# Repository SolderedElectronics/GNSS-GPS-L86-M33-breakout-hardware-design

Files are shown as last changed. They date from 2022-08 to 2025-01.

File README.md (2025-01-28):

# GNSS GPS L86-M33 breakout Hardware Design

## About the Product

| GNSS GPS L86-M33 breakout Image |
| :----------------------------------------------------------: |
| [Buy GNSS GPS L86-M33 breakout](https://www.solde.red/333201) |

Global Navigation Satellite Systems (GNSS), or as we all like to call it “GPS,” enable precise location determination on Earth. Thanks to this module, you can use GNSS for your project and employ the device for asset tracking or create a wearable device. The module is small, energy-efficient, highly effective, and easy to use thanks to its built-in antenna.

L86-M33 is a GNSS receiver, meaning it can receive signals from GPS, GLONASS, and Galileo constellations. Equipped with EASY (Embedded Assist System for self-generated orbit prediction) and AlwaysLocate technologies, the L86-M33 ensures fast and accurate positioning even in challenging environments. Its advanced internal logger, LOCUS, allows you to store your routes and location data.

In addition to the aforementioned L86-M33 module, which has an integrated antenna, our breakout board also has a connector for a CR1220 battery that is used as a backup for timekeeping and GPS data. The module can operate without a battery, but each time it will have to pull data from the satellites anew (cold start). If the integrated antenna is not sufficient, there is an IPX connector on the board for adding an external, stronger antenna. To easily access the pins of the module, the pins are exposed on the board for easy access.

---

## Repository Contents

This repository contains all design files for GNSS GPS L86-M33 breakout, organized as follows:

- **`CAD` folder**: Contains KiCAD design files, including:
  - Schematics
  - PCB layout
  - Panel PCB layout
  - Source 3D files in Fusion360, if any
  - All files are sorted by version with a detailed change log.
- **`OUTPUTS` folder**: Includes all production-ready files, such as:
  - Bill of Materials (BOM) and interactive BOM (iBOM)
  - PDF versions of schematics
  - 3D `.step` file of the board
  - 3D-printable models
  - Gerber files for PCB manufacturing
  - Image of the pinout of the board
  - Product image
  - Compliance, legal and generic sales documents

Refer to the `Change Log` in the CAD folder for details about updates between versions.

---

## Learn More About the Product

Beyond the repository, explore the following resources:

### Soldered Verify

Soldered Verify Logo

The **Soldered Verify** system ensures every board you purchase from Soldered is fully functional. It also provides access to exclusive test data for your product. To get started, find the unique Soldered Verify ID on your product's packaging and enter the ID on the [Soldered Verify page](https://soldered.com/verify/) to access test results and additional product details.

### Soldered Community

soldered-verify-logo

Soldered Community is your go-to place for technical support. Our engineers track and answer all questions posted there, and it’s a great space for the maker community. Get answers to your questions and solutions for your challenges at [Soldered Community](https://soldered.com/community).

### solde.red

solde.red is an ultimate URL shortener and information hub. Access it by typing solde.red/ followed by your product SKU, e.g., [solde.red/333000](https://solde.red/333000), to find getting-started guides, datasheets, open-source hardware and software files, certifications, images, pinouts, and more. Read more about the shortener [here](https://solde.red/info/).

---

## Contributing

Contributions are welcome! Here’s how you can get involved:

- Submit pull requests to enhance the design or fix issues.
- Report bugs or problems by opening an issue.

We encourage community collaboration to make this product even better.

---

## About Soldered

soldered-logo

[Soldered for Makers](https://soldered.com) specializes in designing and manufacturing electronic products tailored for enthusiasts, ranging from hobbyists to professionals. Our portfolio includes electronic boards, sensors, and actuators that are widely utilized in fields such as microelectronics, mechatronics, robotics, programming, and IoT. Every product we offer is designed in-house and built upon open-source hardware and software platforms. Proudly certified and manufactured within the European Union, our catalog likely includes the product you need for your project.

We complement these products with comprehensive tutorials and manuals, product descriptions, schematics, programming codes, and project examples. Our round-the-clock [customer and technical support](https://soldered.com/community) is available for all our products, irrespective of the sales channel. Soldered’s success and services reflect our maker community’s unwavering [trust](https://www.trustpilot.com/review/soldered.com), for which we are deeply grateful. Join our community and create using Soldered products.

---

## License

All Soldered open-source hardware (OSH) is under The TAPR Open Hardware License. Read more in the LICENSE file located in this repository.

**Disclaimer:**

No warranty - all designs in this repository are distributed in the hope that they will be useful, but without any warranty. They are provided "AS IS", therefore without warranty of any kind, either expressed or implied. The entire quality and performance of what you do with the contents of this repository are your responsibility. In no event Soldered Electronics will be liable for your damages, or losses, including any general, special, incidental, or consequential damage arising out of the use or inability to use the contents of this repository. 

---

## Have fun!

Thank you for your support from your fellow makers at Soldered Electronics.

Happy Making!

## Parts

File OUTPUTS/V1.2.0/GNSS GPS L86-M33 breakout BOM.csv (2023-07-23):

Id | Designator | Package | Quantity | Designation | Supplier and ref
1 | K1 | IPX connector with SMA | 1 | IPX connector with SMA
2 | K2 | CR1220_HOLDER | 1 | CR1220_HOLDER
3 | R6 | 0603R | 1 | 47k
4 | H3,H4,H2,H1 | HOLE_3.2mm | 4 | HOLE_3.2mm
5 | R10,R9 | 0402R | 2 | 2k2
6 | U3 | SOT-23-5 | 1 | SE5218
7 | C3,C4 | 0603C | 2 | 2u2
8 | JP3,JP4,JP1 | SMD-JUMPER-CONNECTED_TRACE_SLODERMASK | 3 | SMD-JUMPER-CONNECTED_TRACE_SLODERMASK
9 | C1 | 0603C | 1 | 100n
10 | Q1 | SOT-23-3 | 1 | NPN-SOT-23-3
11 | R4,R5,R3,R8,R7 | 0603R | 5 | 10k
12 | U1 | SOT-363 | 1 | NMOS-DUAL
13 | K3 | HEADER_MALE_8X1 | 1 | HEADER_MALE_8X1
14 | D1,D2 | M4_DIODA | 2 | M4_DIODA
15 | D4 | 0402LED | 1 | blue
16 | R2 | 0603R | 1 | 4k7
17 | U2 | L86-M33 | 1 | L86-M33
18 | R1 | 0603R | 1 | 5k1
19 | C2 | 1206C | 1 | 10u
20 | JP2 | SMD_JUMPER | 1 | SMD_JUMPER
21 | D3 | 0402LED | 1 | purple

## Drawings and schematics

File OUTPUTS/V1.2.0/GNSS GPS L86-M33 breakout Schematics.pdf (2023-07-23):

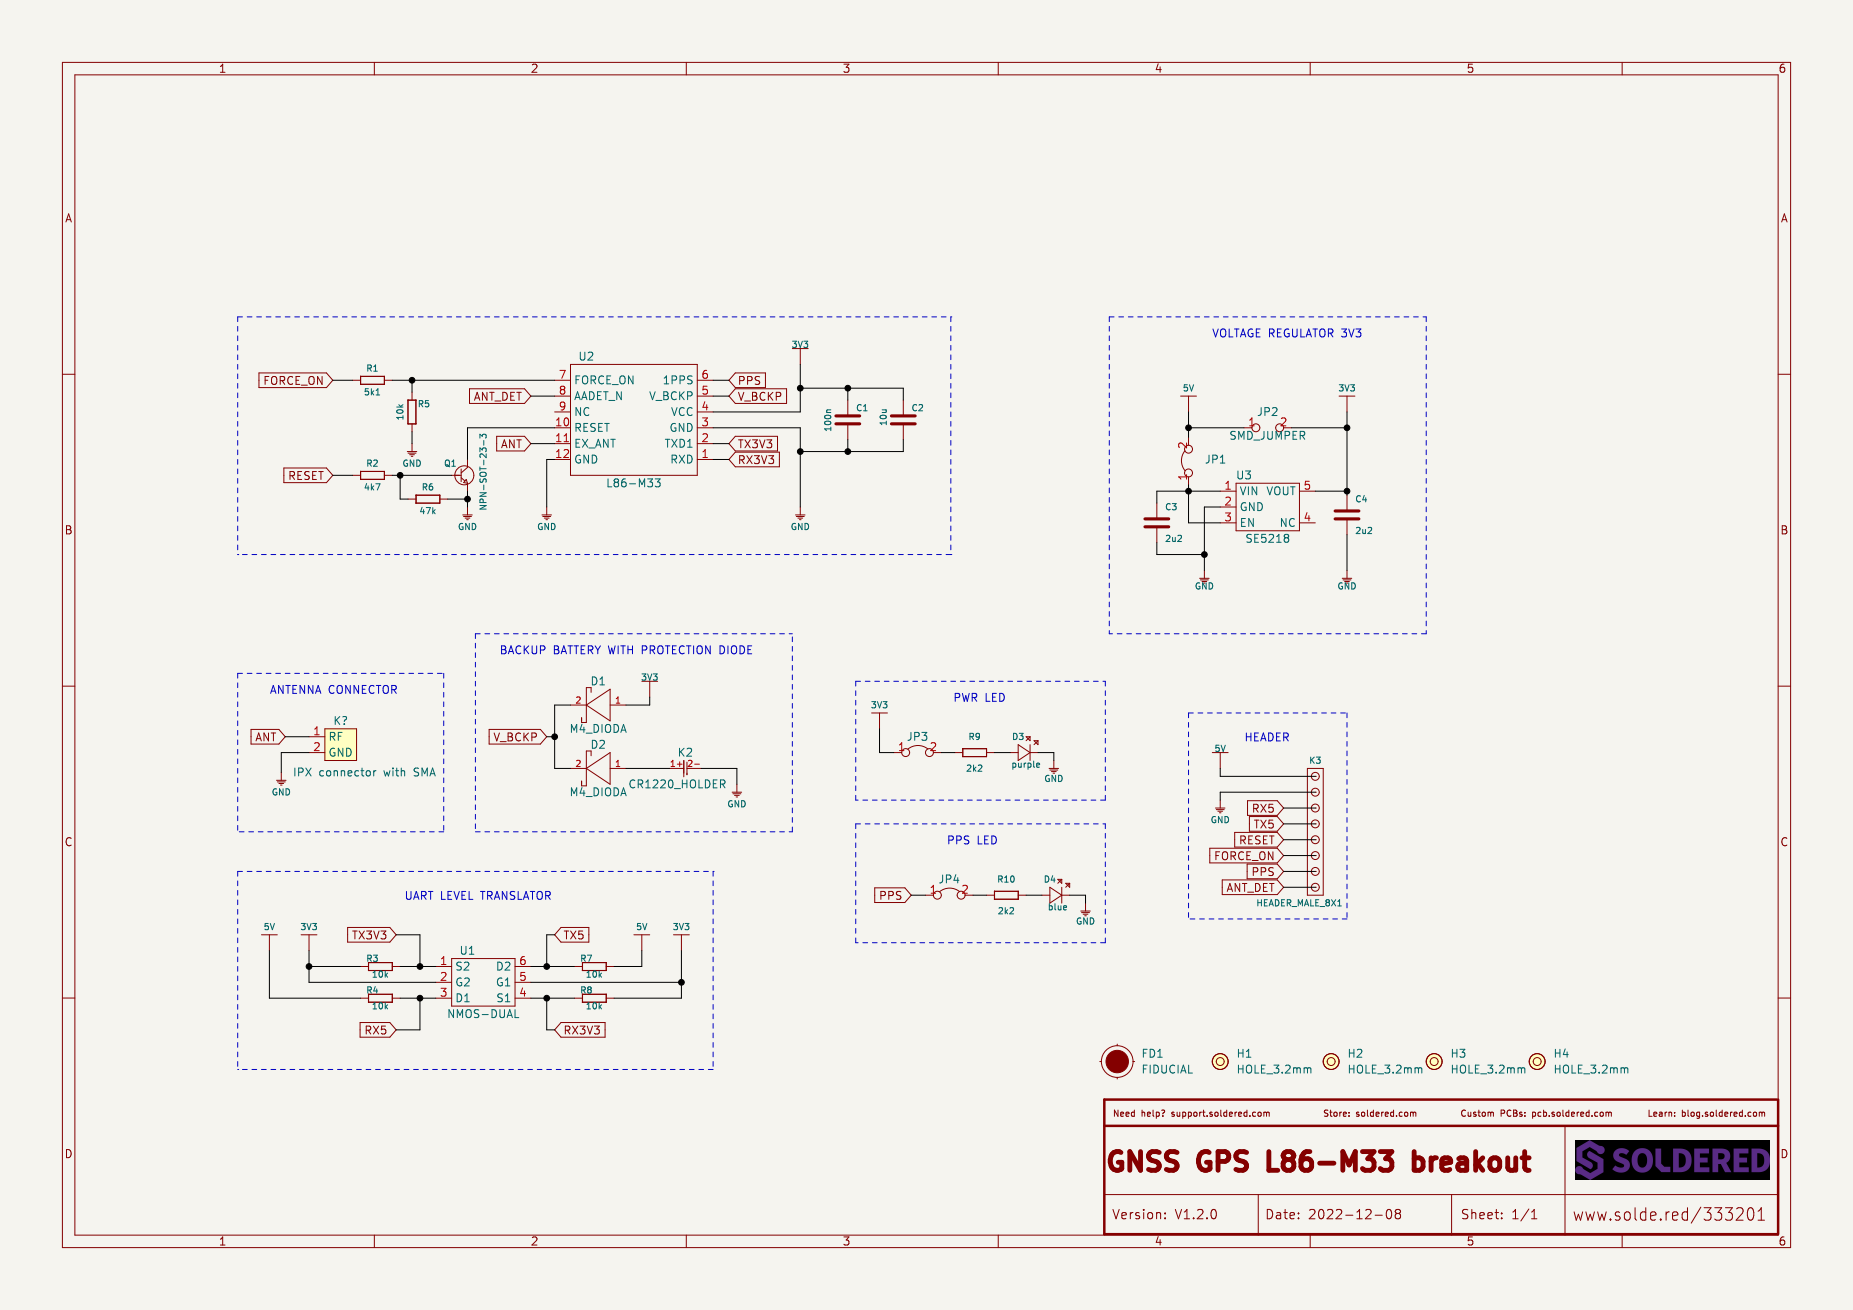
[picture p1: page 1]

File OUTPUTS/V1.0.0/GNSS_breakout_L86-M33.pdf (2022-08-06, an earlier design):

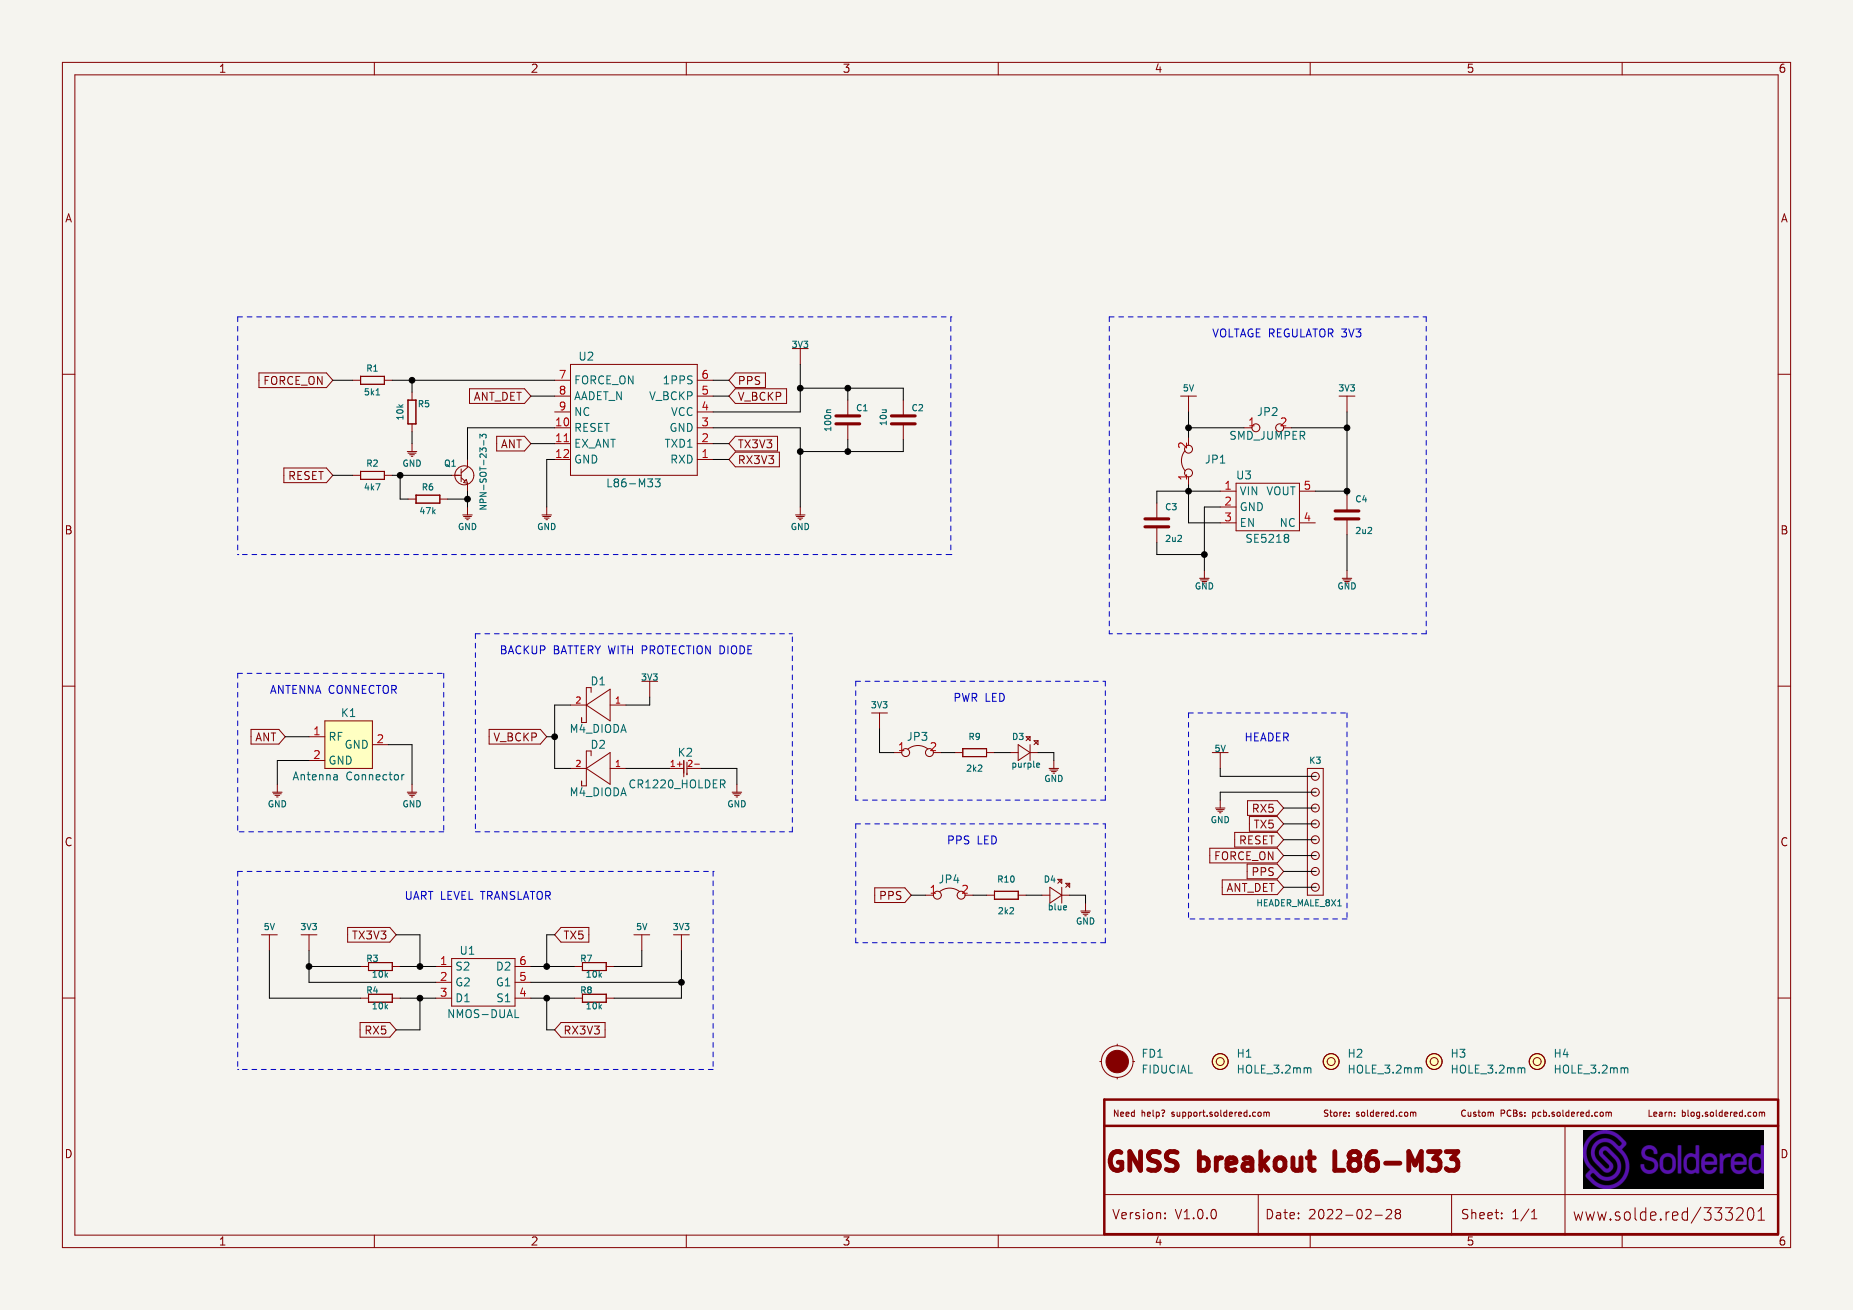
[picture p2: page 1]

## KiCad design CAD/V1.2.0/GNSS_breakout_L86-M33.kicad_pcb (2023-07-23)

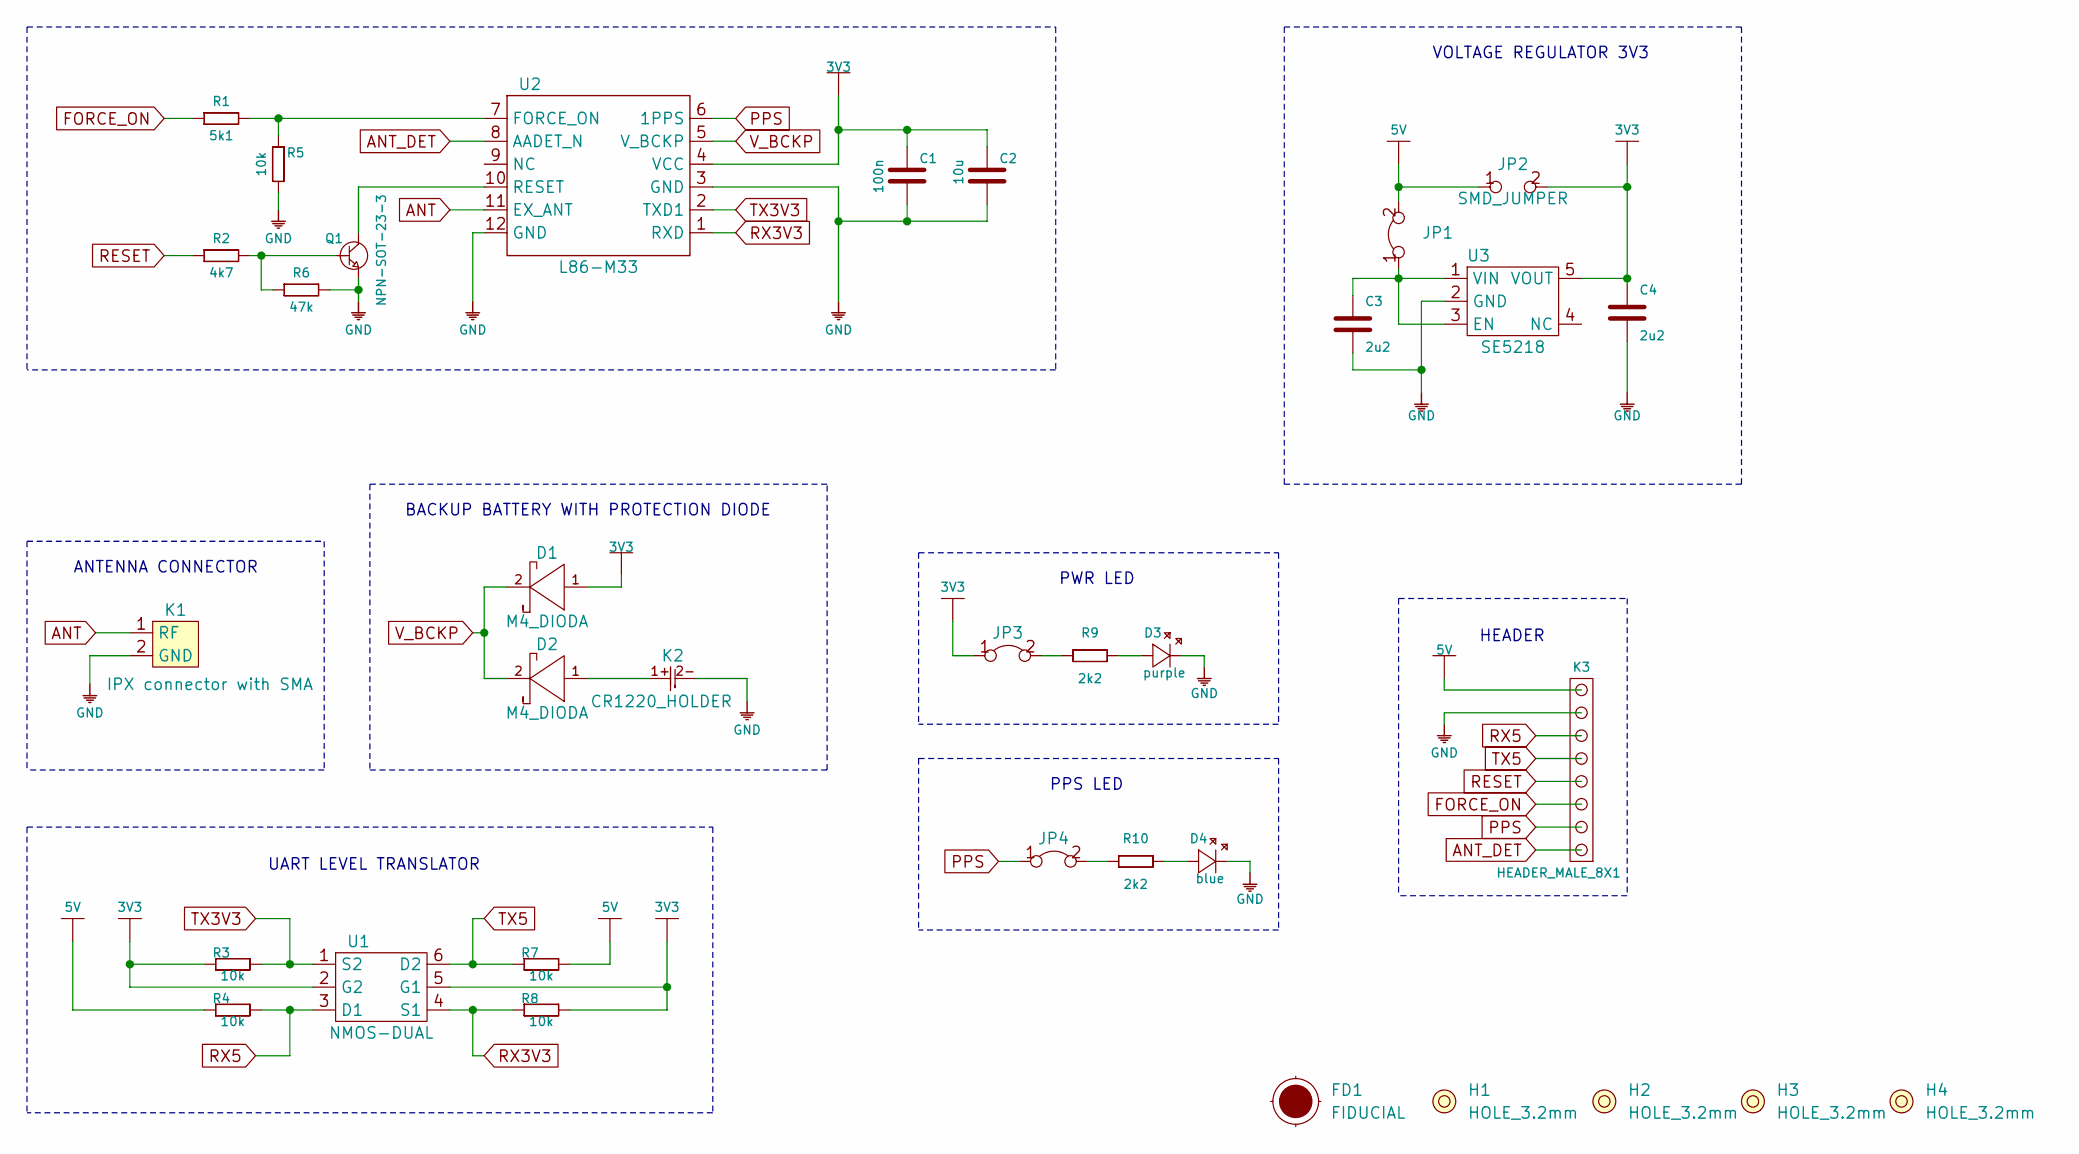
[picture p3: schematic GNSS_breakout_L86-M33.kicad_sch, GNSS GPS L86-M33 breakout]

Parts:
C1: 100n; 0603C
C2: 10u; 1206C
C3, C4: 2u2; 0603C
D1, D2: M4_DIODA
D3: purple; 0402LED
D4: blue; 0402LED
FD1: FIDUCIAL; FIDUCIAL_23
H1, H2, H3, H4: HOLE_3.2mm
JP1, JP3, JP4: SMD-JUMPER-CONNECTED_TRACE_SLODERMASK
JP2: SMD_JUMPER
K1: IPX connector with SMA
K2: CR1220_HOLDER
K3: HEADER_MALE_8X1
Q1: NPN-SOT-23-3; SOT-23-3
R1: 5k1; 0603R
R2: 4k7; 0603R
R3, R4, R5, R7, R8: 10k; 0603R
R6: 47k; 0603R
R9, R10: 2k2; 0402R
U1: NMOS-DUAL; SOT-363
U2: L86-M33
U3: SE5218; SOT-23-5

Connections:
3V3: C1.2, C2.2, C4.2, D1.1 (A), JP2.2, JP3.1, R3.1, R8.2, U1.2 (G2), U1.5 (G1), U2.4 (VCC), U3.5 (VOUT)
5V: JP1.2, JP2.1, K3.8, R4.1, R7.2
ANT: K1.1 (RF), U2.11 (EX_ANT)
ANT_DET: K3.1, U2.8 (AADET_N)
FORCE_ON: K3.3, R1.1
GND: C1.1, C2.1, C3.1, C4.1, D3.2 (K), D4.2 (K), K1.2 (GND), K2.2-, K3.7, Q1.2 (E), R5.2, R6.2, U2.3 (GND), U2.12 (GND), U3.2 (GND)
unnamed: C3.2, JP1.1, U3.1 (VIN), U3.3 (EN)
unnamed: D2.1 (A), K2.1+
unnamed: D3.1 (A), R9.2
unnamed: D4.1 (A), R10.2
unnamed: JP3.2, R9.1
unnamed: JP4.2, R10.1
unnamed: Q1.1 (B), R2.2, R6.1
unnamed: Q1.3 (C), U2.10 (RESET)
unnamed: R1.2, R5.1, U2.7 (FORCE_ON)
PPS: JP4.1, K3.2, U2.6 (1PPS)
RESET: K3.4, R2.1
RX3V3: R8.1, U1.4 (S1), U2.1 (RXD)
RX5: K3.6, R4.2, U1.3 (D1)
TX3V3: R3.2, U1.1 (S2), U2.2 (TXD1)
TX5: K3.5, R7.1, U1.6 (D2)
V_BCKP: D1.2 (K), D2.2 (K), U2.5 (V_BCKP)

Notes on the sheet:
ANTENNA CONNECTOR
PPS LED
VOLTAGE REGULATOR 3V3
BACKUP BATTERY WITH PROTECTION DIODE
UART LEVEL TRANSLATOR
PWR LED
HEADER

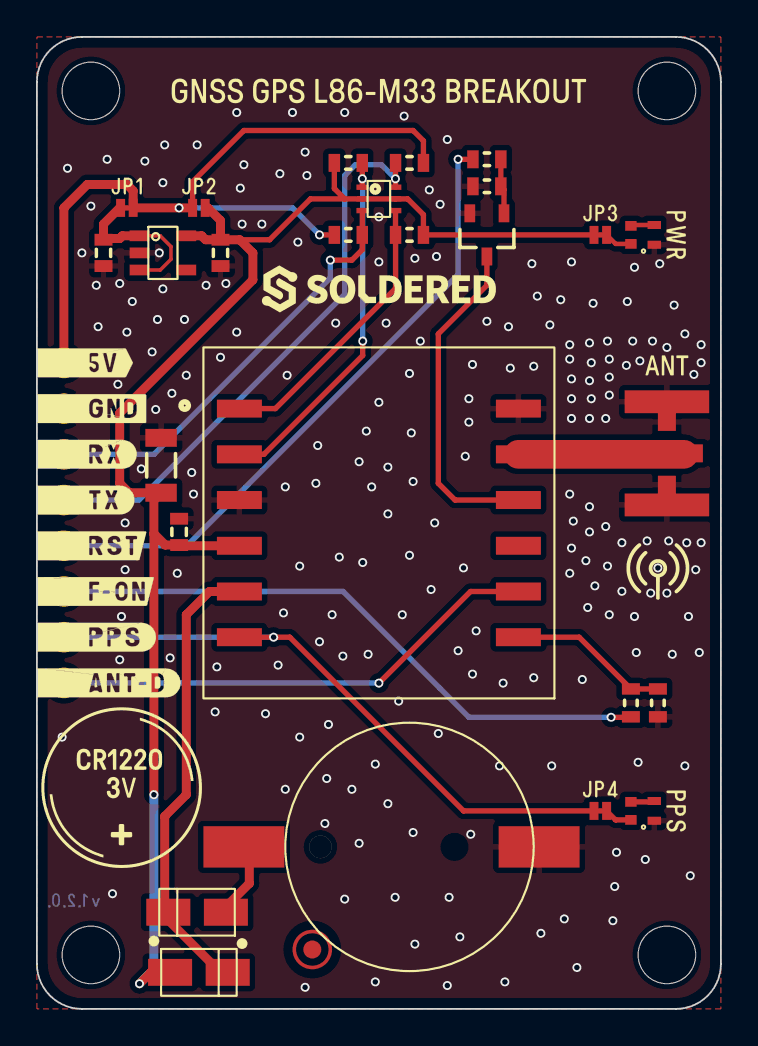
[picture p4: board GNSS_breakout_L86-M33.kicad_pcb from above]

Board: 2 copper layers, 38.0 x 54.0 mm, 36 parts (0 on the bottom side), 22 nets.

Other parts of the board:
kibuzzard-62FB46FA: G***; kibuzzard-62FB46FA
kibuzzard-6391DAF4: G***; kibuzzard-6391DAF4

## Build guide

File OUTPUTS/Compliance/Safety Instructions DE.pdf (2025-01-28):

BITTE BEWAHREN SIE DIESE INFORMATIONEN ZUR SPÄTEREN VERWENDUNG AUF.
LESEN SIE VOR DER VERWENDUNG DIESES PRODUKTS ALLE ANWEISUNGEN IN DOKUMENT. Produktname: GNSS GPS L86-M33 breakout
Die ersten Schritte:Besuchen Sie www.soldered.com, um loszulegen.

## WARNUNGEN

- Dieses Produkt sollte nicht abgedeckt werden und in einer gut belüfteten Umgebung betrieben werden.
- Das Produkt sollte auf einer stabilen, flachen, nicht leitenden Oberfläche aufgestellt werden und nicht mit leitenden Gegenständen in Berührung kommen.
- Der Anschluss anderer Geräte kann die Konformität beeinträchtigen oder zu Schäden am Gerät führen und zum Erlöschen der Garantie führen.
- Wenn Peripheriegeräte angeschlossen werden, die nicht das Kabel oder den Stecker enthalten, muss das verwendete Kabel oder muss das verwendete Kabel bzw. der verwendete Steckverbinder eine angemessene Isolierung und Funktion aufweisen, damit die Anforderungen die einschlägigen Leistungs- und Sicherheitsanforderungen erfüllt werden.
- Es besteht Explosionsgefahr, wenn die Batterie falsch eingesetzt wird.
- Das Produkt sollte nicht außerhalb des angegebenen Arbeitsbereichs verwendet werden.

## HINWEISE ZUR SICHEREN ANWENDUNG

Um Fehlfunktionen oder Schäden an Ihrem Gerät zu vermeiden, beachten Sie bitte die folgenden Hinweise:
- Setzen Sie das Gerät nicht Wasser oder Feuchtigkeit aus und stellen Sie es nicht auf eine
leitende Oberfläche, wenn es eingeschaltet ist. Das Gerät nicht mit nassen Händen anfassen.
- Setzen Sie es keiner Wärmequelle aus; das Produkt ist für die Verwendung bei normalen Raumtemperaturen ausgelegt. Das Produkt ist für die Verwendung in Innenräumen vorgesehen.
- Seien Sie bei der Handhabung vorsichtig, um mechanische oder elektrische Schäden an Teilen des Geräts zu vermeiden. Fassen Sie das Gerät nicht an, wenn es unter Spannung steht. Verwenden Sie einen ESD-Schutz.
- Verwenden Sie nur das mitgelieferte Kabel (oder ein gleich- oder höherwertiges Kabel)
mit dem Gerät.

## COMPLIANCE-INFORMATIONEN

Das Produkt entspricht den entsprechenden Bestimmungen der RoHS-Richtlinie für die Europäische Union. Wie alle elektrischen und elektronischen Geräte (EEE), sollte das Produkt nicht über den Hausmüll entsorgt werden.
ELEKTROMAGNETISCHE VERTRÄGLICHKEIT UND BETRIEB
- Das Produkt entspricht den Schutzanforderungen der Richtlinie des EU-Rates 2014/30/EU über die Rechtsvorschriften der Mitgliedstaaten zur elektromagnetischen Verträglichkeit und den Elektromagnetische Verträglichkeitsverordnung 2016 des Vereinigten Königreichs.
- WARNUNG: Bitte verändern Sie nicht das Design dieses Produkts, da dies dazu führen kann, dass Sie das Produkt nicht mehr uneingeschränkt nutzen können.
Dies gilt auch für die Änderung der Frequenz, mit der das Produkt arbeitet.

## Einhaltung gesetzlicher Vorschriften und wichtige

Soldered Electronics d.o.o., Vinkovačka cesta 68, 31000 Osijek, Croatia. VAT ID: HR83200237288

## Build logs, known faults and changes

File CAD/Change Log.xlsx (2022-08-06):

CHANGE LOG
 | Latest version |  |  | v1.0.0.
 |  | Product name: |  | GNSS breakout L86-M33
 |  | Release date: |  | 28.02.2022.
 |  | Release author: |  | Ivan Fadiga
Version: | v1.0.0. | Author: | Ivan Fadiga | Date: | 28.2.2022.
List of Changes
 | Initial document
Version: |  | Author: |  | Date:
List of Changes
Version: |  | Author: |  | Date:
List of Changes

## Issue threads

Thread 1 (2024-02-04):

Prijedlog za nadopunu README.md

sbravar, 2024-02-04:
https://github.com/SolderedElectronics/GNSS-GPS-L86-M33-breakout-hardware-design/blob/1bc7b23ac9562bf88b86c5d5c11397a9f29d28c2/README.md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

umjesto:

## --- Product name --- Hardware design

predlažem:

# GNSS GPS L86-M33 breakout Hardware design

https://github.com/SolderedElectronics/GNSS-GPS-L86-M33-breakout-hardware-design/blob/1bc7b23ac9562bf88b86c5d5c11397a9f29d28c2/README.md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

umjesto:

| 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 |

predlažem:

| 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 |

https://github.com/SolderedElectronics/GNSS-GPS-L86-M33-breakout-hardware-design/blob/1bc7b23ac9562bf88b86c5d5c11397a9f29d28c2/README.md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

umjesto:

|      [--- product name ----](https://www.solde.red/SKU)      |

predlažem:

|      [Buy GNSS GPS L86-M33 breakout](https://www.solde.red/333201)      |

https://github.com/SolderedElectronics/GNSS-GPS-L86-M33-breakout-hardware-design/blob/1bc7b23ac9562bf88b86c5d5c11397a9f29d28c2/README.md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

umjesto:

------ product description ------

predlažem:

Global Navigation Satellite Systems (GNSS), or as we all like to call it “GPS,” enable precise location determination on Earth. Thanks to this module, you can use GNSS for your project and employ the device for asset tracking or create a wearable device. The module is small, energy-efficient, highly effective, and easy to use thanks to its built-in antenna.

L86-M33 is a GNSS receiver, meaning it can receive signals from GPS, GLONASS, and Galileo constellations. Equipped with EASY (Embedded Assist System for self-generated orbit prediction) and AlwaysLocate technologies, the L86-M33 ensures fast and accurate positioning even in challenging environments. Its advanced internal logger, LOCUS, allows you to store your routes and location data.

In addition to the aforementioned L86-M33 module, which has an integrated antenna, our breakout board also has a connector for a CR1220 battery that is used as a backup for timekeeping and GPS data. The module can operate without a battery, but each time it will have to pull data from the satellites anew (cold start). If the integrated antenna is not sufficient, there is an IPX connector on the board for adding an external, stronger antenna. You can find the antenna we recommend [here](https://soldered.com/product/active-gps-antenna-sma-connector/). To easily access the pins of the module, the pins are exposed on the board for easy access.

rsoric, 2024-02-05:
Hello, and thank you for your feedback. We are currently working on automating this process. Soon, all repositories will be updated with the real content. Cheers!

Closed 2024-02-05.
